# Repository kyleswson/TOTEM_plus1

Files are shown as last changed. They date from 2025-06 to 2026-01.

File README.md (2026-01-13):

<picture align="center">
  <source media="(prefers-color-scheme: dark)" srcset="/docs/images/TOTEM_logo_dark.svg">
  <source media="(prefers-color-scheme: light)" srcset="/docs/images/TOTEM_logo_bright.svg">
  TOTEM logo
</picture>

<h1 align="center">T O T E M</h1>

TOTEM is a 38 key column-staggered choc split keyboard. It is meant to be used with a [Seeed Studio XIAO nRF52840 BLE](https://www.seeedstudio.com/Seeed-XIAO-BLE-nRF52840-p-5201.html) or [XIAO RP2040](https://www.seeedstudio.com/XIAO-RP2040-v1-0-p-5026.html).
It was created for the SEEED XIAO keyboard contest.\
[Here](https://www.hackster.io/geist/totem-a-tiny-splitkeyboard-with-splay-cb2e43) you can read about the process of making it.

## Companion Totem (TOTEM+1)
Totem+1 is a modified version of TOTEM by GEIGEIGEIST. It has additional one key on inner index column of each side (total 40 keys). This is because typing in Korean needs the "B" key on the right hand side. So I added additional B key on the right. And to make this keyboard symmetrical, I added it on the left side too. 

The inner thumb keys have been replaced to [EVQWGD001 roller encoders](https://a.aliexpress.com/_c3mfh3fF). Thought this will be handy for navigating cursor while typing. These are very expensive now(25$ for 1) but luckily I got it for 5$ each few years ago. \
I also found some alternatives that you can consider. But you may need to edit the PCB since the footprint will be different.\
https://github.com/kumamuk-git/CKW12 \
https://github.com/Taro-Hayashi/THQWGD001 \
https://github.com/EverydayErgo/MEH01 

For the batteries, I used this [305060 1100mAh battery](https://a.aliexpress.com/_c3kIPq6d) since I wanted long battery life. 

***

## LAYOUT

TOTEM layout

***

## PCB

[Here](/PCB/) you can find the KiCad files and Gerbers for the TOTEM.

***

## CASE

You can use the TOTEM without a case, but [here](/case/) you can find one I made for it.

***

## BUILD GUIDE

The build guide for the TOTEM can be found [here](/docs/buildguide.md).

***

## FIRMWARE

[QMK (VIAL) precompiled](/firmware/QMK/) or [QMK (VIAL) source](/firmware/QMK/VIAL_source/) for the TOTEM (wired using the XIAO RP2040)\
[ZMK precompiled](/firmware/ZMK/) or [ZMK source (outdated)](https://github.com/GEIGEIGEIST/zmk-config-totem) for the TOTEM (wireless using the XIAO BLE)

***

## BUY

You can buy TOTEM kits and finished builds on [keeb.supply](https://keeb.supply/products/geist-totem) (based in Germany)

***

## PHOTOS

This is the TOTEM in a black resin case

TOTEM black resin\
TOTEM black resin\
TOTEM black resin

This is the TOTEM with a black resin tenting bottom plate

TOTEM black resin tenting\
[Video by *Wolfgang's Channel* showing the tenting system in action](https://youtu.be/rvM2BthjEI4?si=mTJVdPeZstshnDyo)

***

## CREDITS

### INSPIRATION

I've added the additional pinky key to make the TOTEM compatible with the layout boards like the [Balbuzard](https://github.com/brow/balbuzard) by [Tom Brow](https://github.com/brow) and the [Osprette](https://github.com/smores56/osprette) by [Sam Mohr](https://github.com/smores56) use, where you put the keybinding of the top left and right keys on an outer pinky key.

### HELP FIXING THINGS

People who helped me create this board and fix stuff

#### PCB
- [Marco "Bob"](https://github.com/GroooveBob)

#### CASE
- [Freya](https://github.com/freya-irl)
- [Bubbleology](https://github.com/bubbleology)

#### FIRMWARE
- [Cem Aksoylar](https://github.com/caksoylar)
- [Grinnie](https://github.com/regicidalplutophage)
- [Alaa Saad Mansour](https://github.com/AlaaSaadAbdo)
- [pekudzu](https://github.com/pekudzu)

If you build a TOTEM I would be pretty happy to see some pictures. And if you want to leave me a tip you can do this [here](https://ko-fi.com/geigeigeist) (but please don't feel pressured)

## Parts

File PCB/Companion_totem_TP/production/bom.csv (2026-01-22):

Designator | Footprint | Quantity | Value | LCSC Part #
BAT+1 | BatteryPad | 1 | +
BATGND1 | BatteryPad | 1 | -
DL1, DL10, DL11, DL12, DL13, DL14, DL15, DL16, DL17, DL18, DL19, DL2, DL20, DL3, DL4, DL5, DL6, DL7, DL8, DL9 | Diode_SOD123 | 20 | D_Small
ENCL17 | RollerEncoder+SW_horizontal | 1 | RotaryEncoder_Switch
J1 | JST_PH_reversible | 1 | Conn_01x02_Socket
PSW1 | MSK12C02 | 1 | SW_SPDT
RSW1 | SKHLLCA010 | 1 | SW_Push
SWL1, SWL10, SWL11, SWL12, SWL13, SWL14, SWL15, SWL16, SWL18, SWL19, SWL2, SWL20, SWL3, SWL4, SWL5, SWL6, SWL7, SWL8, SWL9 | SW_Hotswap_Kailh_Choc_V1V2 | 19 | SW_Push_45deg
U1 | xiao-ble-smd-cutout | 1 | xiao-ble

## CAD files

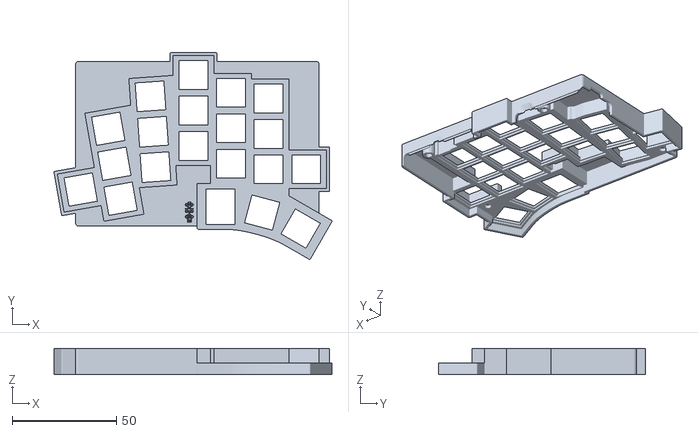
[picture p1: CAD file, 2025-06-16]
case/Totem_rollin/Totem_rollin_top_left.stl
133.1 x 99.0 x 12.5

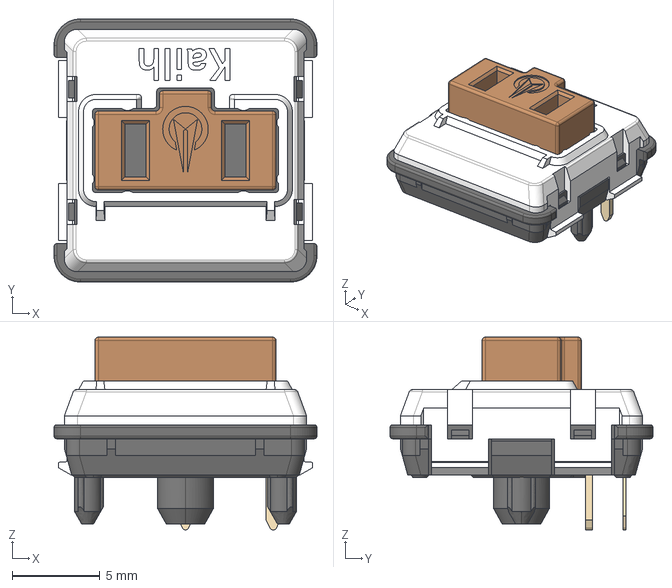
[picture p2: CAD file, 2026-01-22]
PCB/Companion_totem_TP/TOTEM3D/SW_Kailh_Choc_V1.stp
15.0 x 15.0 x 11.0 mm

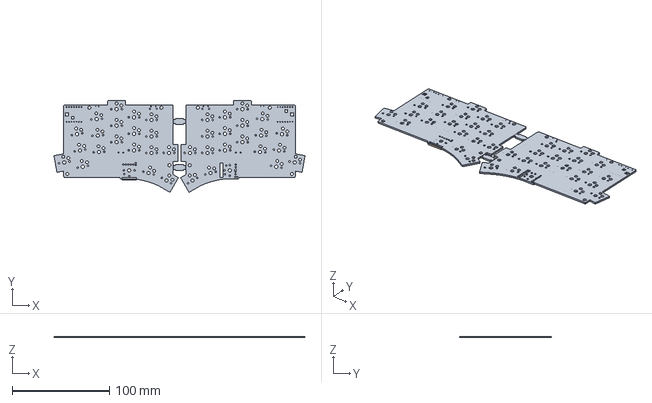
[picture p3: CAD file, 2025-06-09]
PCB/totem_0_2.step
258.7 x 94.4 x 1.51 mm
Totem_rollin_PCB_1
Totem_rollin_PCB_2

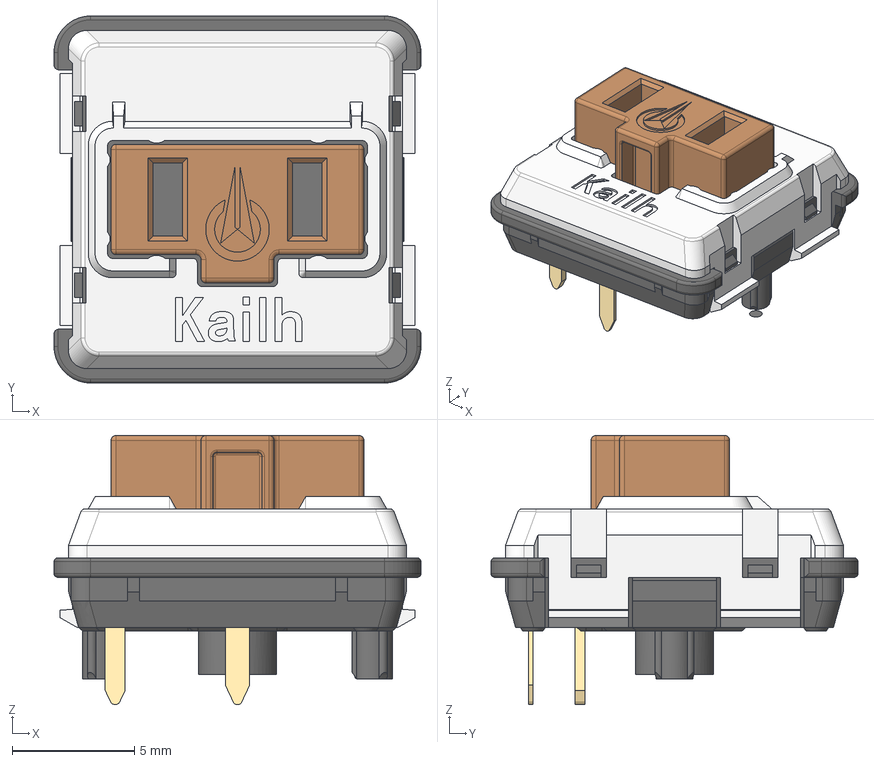
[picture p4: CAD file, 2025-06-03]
PCB/Companion_totem_TP/TOTEM3D/Kailh_switch_PG1350_optional.step
15.0 x 15.0 x 11.0 mm

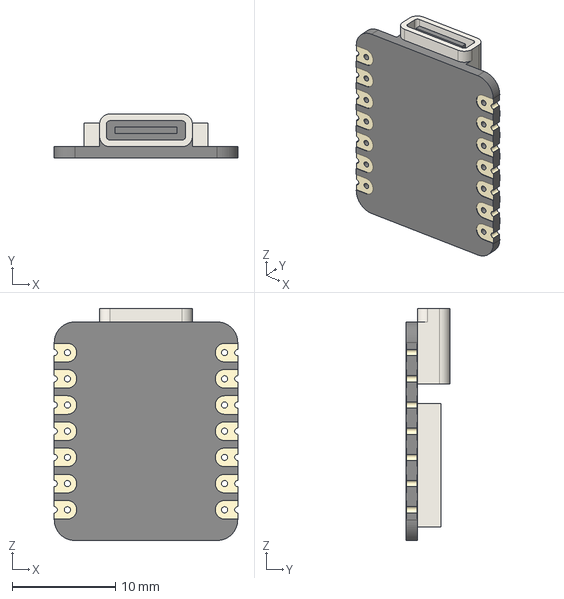
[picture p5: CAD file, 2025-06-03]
PCB/Companion_totem_TP/TOTEM3D/xiao-ble-tht.step
17.8 x 4.27 x 22.5 mm

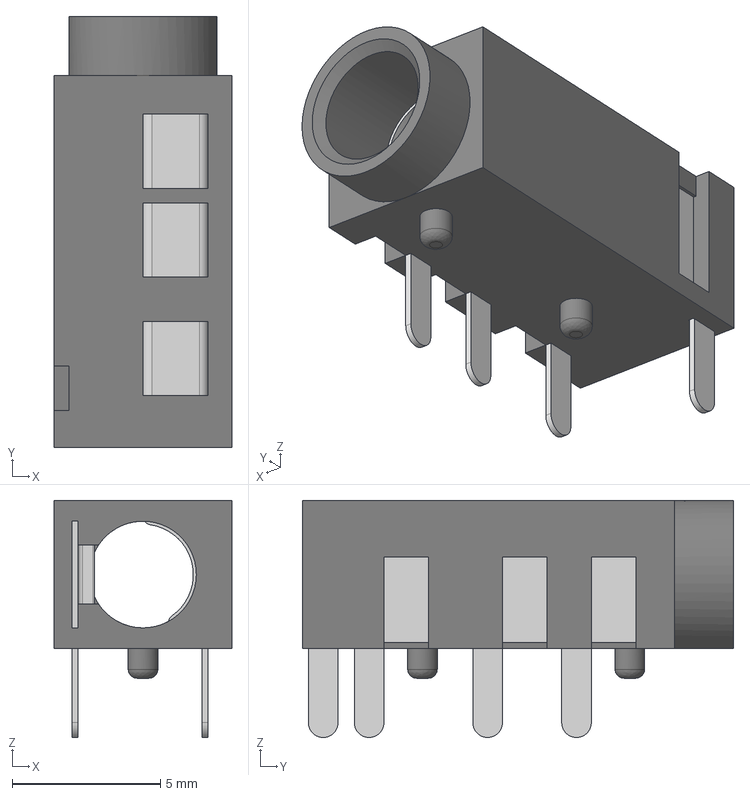
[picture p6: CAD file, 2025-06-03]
PCB/Companion_totem_TP/TOTEM3D/PJ320A.STEP
6.00 x 14.6 x 8.00 mm

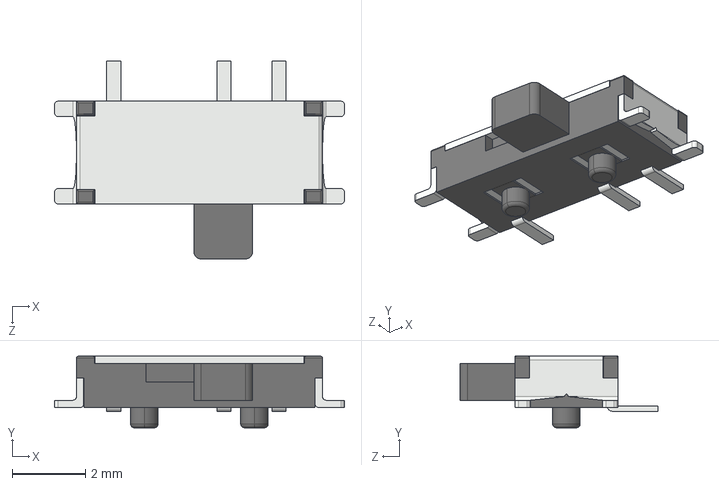
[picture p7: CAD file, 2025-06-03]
PCB/Companion_totem_TP/TOTEM3D/MSK12C02.STEP
7.90 x 1.95 x 5.39 mm

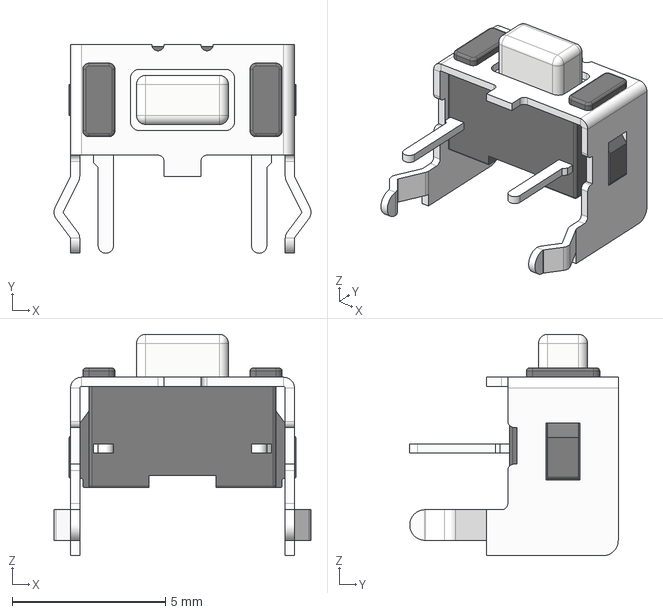
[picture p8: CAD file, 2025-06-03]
PCB/Companion_totem_TP/TOTEM3D/SW_SKHLLC.step
8.38 x 6.80 x 7.22 mm

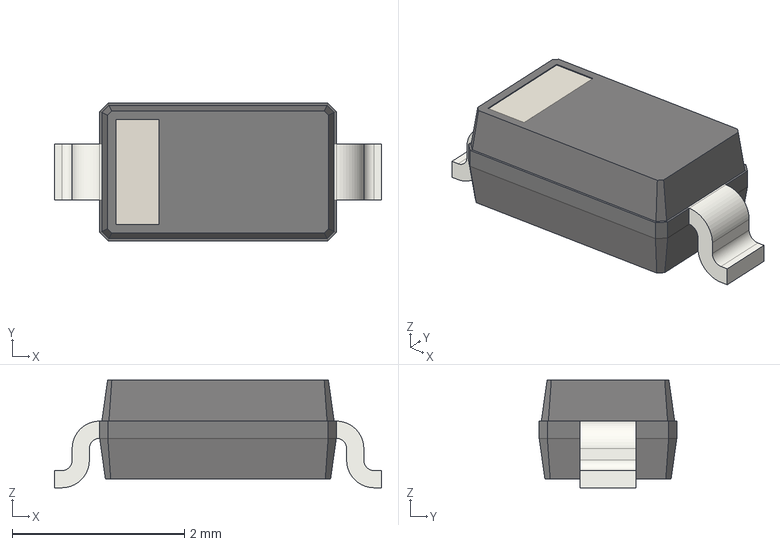
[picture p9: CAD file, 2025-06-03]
PCB/Companion_totem_TP/TOTEM3D/D_SOD-123.step
3.80 x 1.60 x 1.25 mm

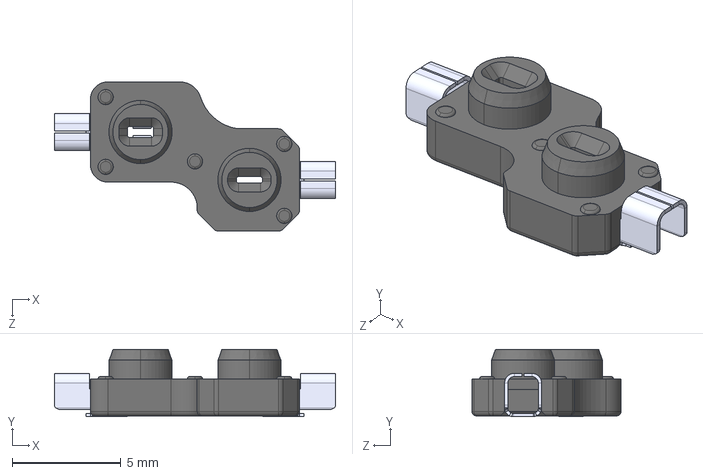
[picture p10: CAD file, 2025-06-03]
PCB/Companion_totem_TP/TOTEM3D/Kailh_socket_PG1350_optional.STEP
12.9 x 3.09 x 6.85 mm
pin x 2
socket

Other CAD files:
case/Totem_rollin/TOTEM_ROLLIN_case_ble.f3d

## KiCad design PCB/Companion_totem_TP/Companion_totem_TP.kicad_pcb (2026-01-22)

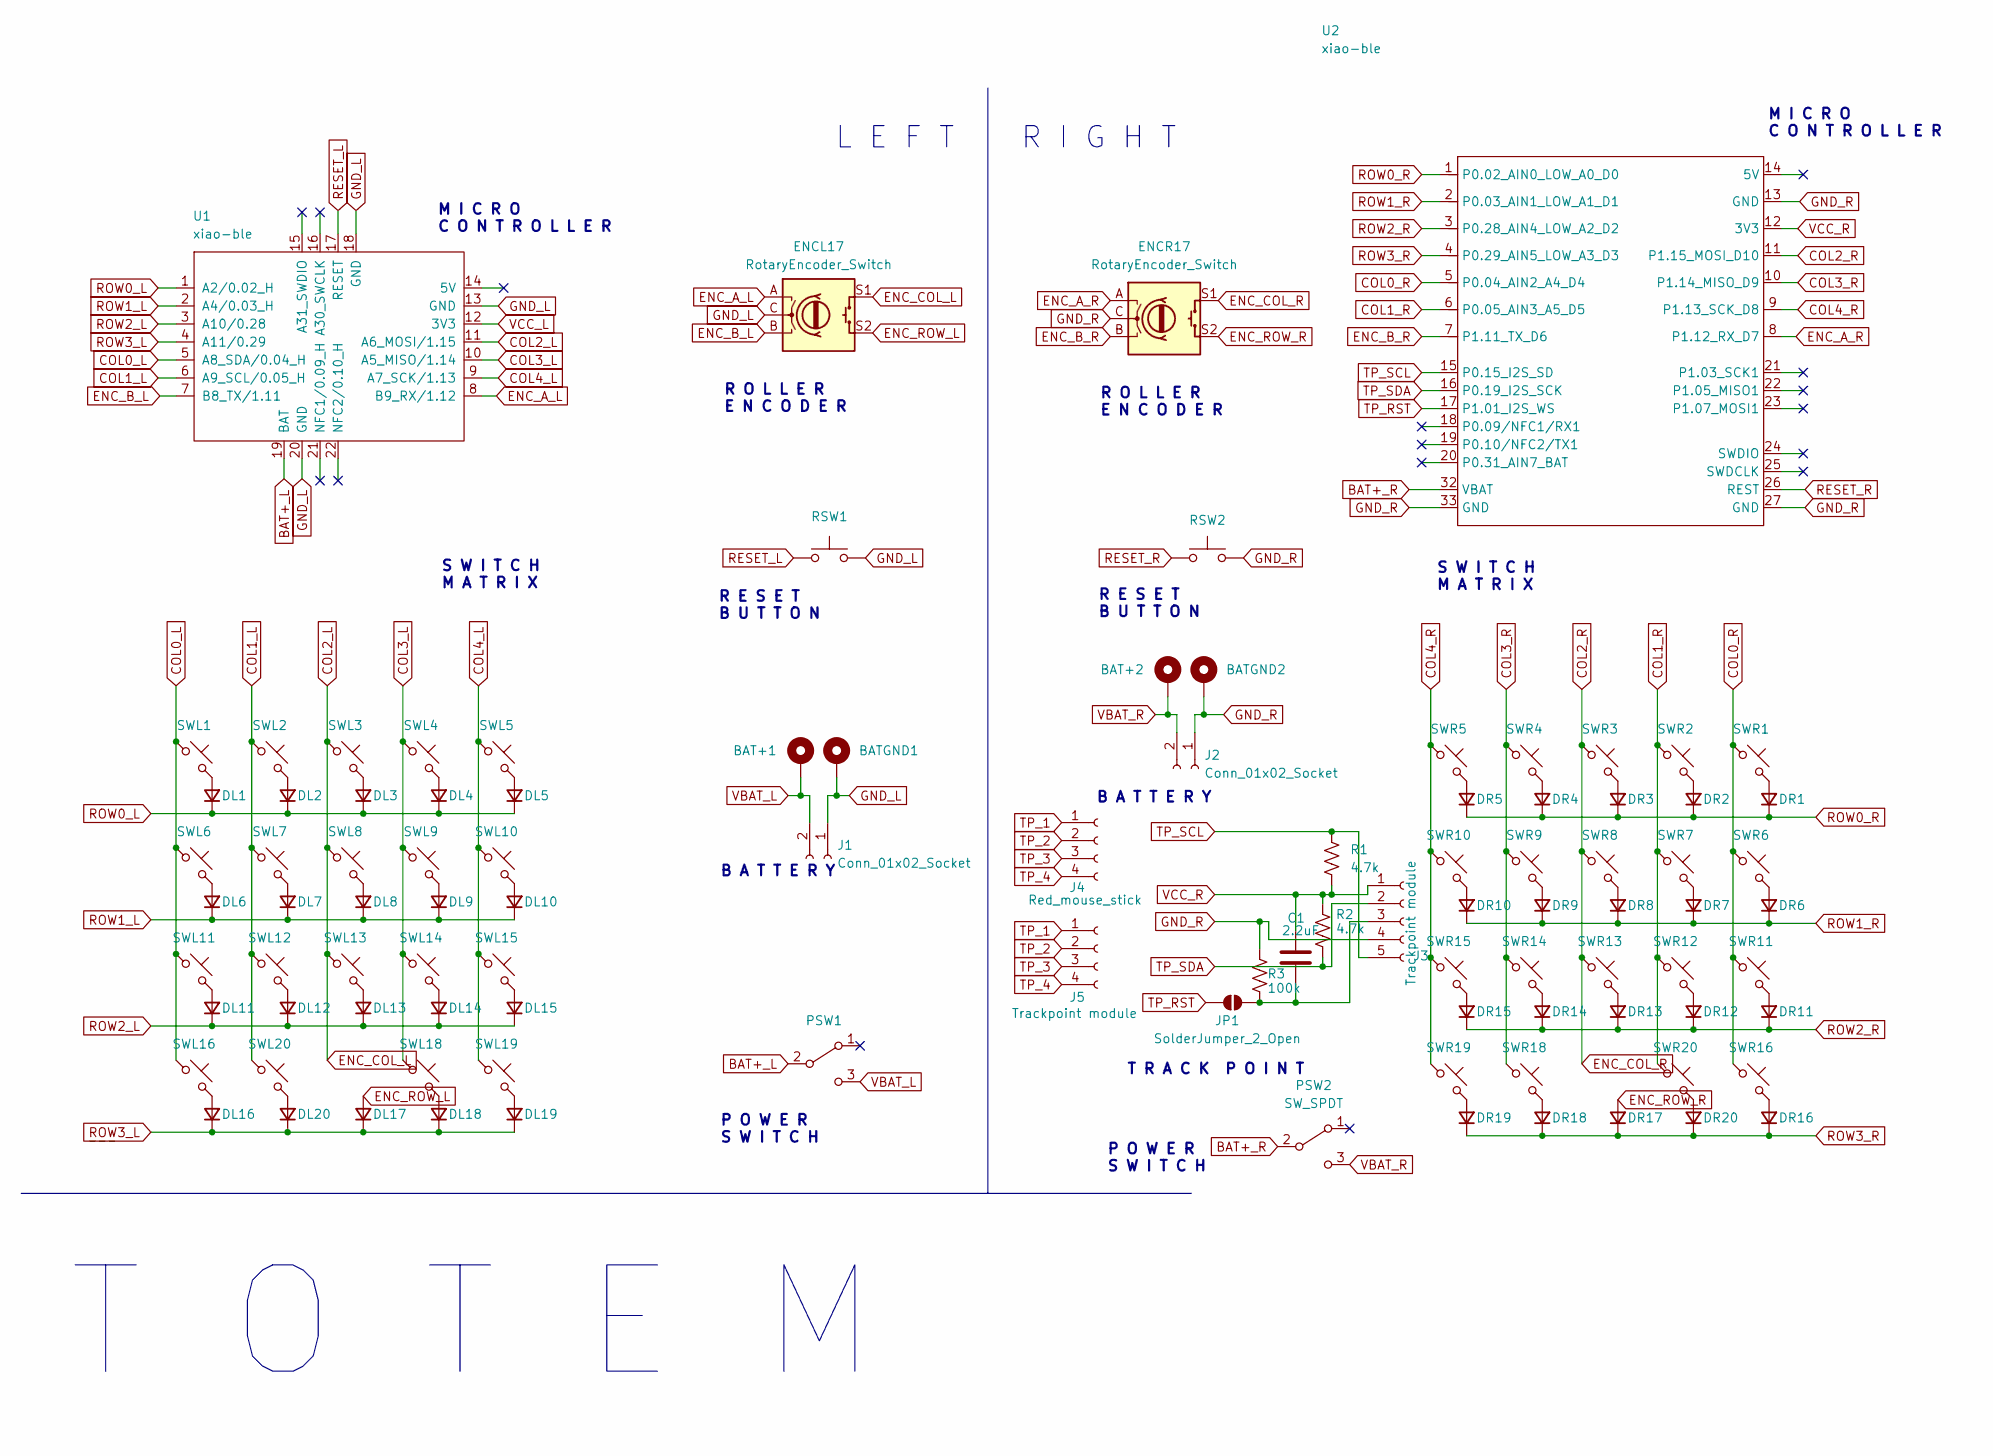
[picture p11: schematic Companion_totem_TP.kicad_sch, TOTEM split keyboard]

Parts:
BAT+1, BAT+2: +; BatteryPad
BATGND1, BATGND2: -; BatteryPad
C1: 2.2uF; C_0603_1608Metric_Pad1.08x0.95mm_HandSolder
DL1, DL2, DL3, DL4, DL5, DL6, DL7, DL8, DL9, DL10, DL11, DL12, DL13, DL14, DL15, DL16, DL17, DL18, DL19, DL20: D_Small; Diode_SOD123
DR1, DR2, DR3, DR4, DR5, DR6, DR7, DR8, DR9, DR10, DR11, DR12, DR13, DR14, DR15, DR16, DR17, DR18, DR19, DR20: D_Small; Diode_SOD123
ENCL17: RotaryEncoder_Switch; RollerEncoder+SW_horizontal
ENCR17: RotaryEncoder_Switch; RollerEncoder_SW_Vertical
J1, J2: Conn_01x02_Socket
J3: Trackpoint module; PinSocket_1x05_P2.54mm_Vertical
J4: Red_mouse_stick; T460S_TP
J5: Trackpoint module; TP_input
JP1: SolderJumper_2_Open; Jumper
PSW1, PSW2: SW_SPDT; MSK12C02
R1, R2: 4.7k; R_0603_1608Metric_Pad0.98x0.95mm_HandSolder
R3: 100k; R_0603_1608Metric_Pad0.98x0.95mm_HandSolder
RSW1, RSW2: SW_Push; SKHLLCA010
SWL1, SWL2, SWL3, SWL4, SWL5, SWL6, SWL7, SWL8, SWL9, SWL10, SWL11, SWL12, SWL13, SWL14, SWL15, SWL16, SWL18, SWL19, SWL20: SW_Push_45deg; Kailh_socket_PG1350
SWR1, SWR2, SWR3, SWR4, SWR5, SWR6, SWR7, SWR8, SWR9, SWR10, SWR11, SWR12, SWR13, SWR14, SWR15, SWR16, SWR18, SWR19, SWR20: SW_Push_45deg; Kailh_socket_PG1350
U1: xiao-ble; xiao-ble-smd-cutout
U2: xiao-ble; XIAO-nRF52840-Plus-SMD

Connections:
BAT+_L: PSW1.2 (B), U1.19 (BAT)
BAT+_R: PSW2.2 (B), U2.32 (VBAT)
COL0_L: SWL1.1, SWL6.1, SWL11.1, SWL16.1, U1.5 (A8_SDA/0.04_H)
COL0_R: SWR1.1, SWR6.1, SWR11.1, SWR16.1, U2.5 (P0.04_AIN2_A4_D4)
COL1_L: SWL2.1, SWL7.1, SWL12.1, SWL20.1, U1.6 (A9_SCL/0.05_H)
COL1_R: SWR2.1, SWR7.1, SWR12.1, SWR20.1, U2.6 (P0.05_AIN3_A5_D5)
COL2_L: ENCL17.S1, SWL3.1, SWL8.1, SWL13.1, U1.11 (A6_MOSI/1.15)
COL2_R: ENCR17.1, ENCR17.2, ENCR17.S1, SWR3.1, SWR8.1, SWR13.1, U2.11 (P1.15_MOSI_D10)
COL3_L: SWL4.1, SWL9.1, SWL14.1, SWL18.1, U1.10 (A5_MISO/1.14)
COL3_R: SWR4.1, SWR9.1, SWR14.1, SWR18.1, U2.10 (P1.14_MISO_D9)
COL4_L: SWL5.1, SWL10.1, SWL15.1, SWL19.1, U1.9 (A7_SCK/1.13)
COL4_R: SWR5.1, SWR10.1, SWR15.1, SWR19.1, U2.9 (P1.13_SCK_D8)
ENC_A_L: ENCL17.A, U1.8 (B9_RX/1.12)
ENC_A_R: ENCR17.A, U2.8 (P1.12_RX_D7)
ENC_B_L: ENCL17.B, U1.7 (B8_TX/1.11)
ENC_B_R: ENCR17.B, U2.7 (P1.11_TX_D6)
ENC_ROW_L: DL17.2 (A), ENCL17.S2
ENC_ROW_R: DR17.2 (A), ENCR17.1, ENCR17.2, ENCR17.S2
GND_L: BATGND1.1, ENCL17.C, J1.1, RSW1.2, U1.13 (GND), U1.18 (GND), U1.20 (GND)
GND_R: BATGND2.1, ENCR17.C, J2.1, J3.4, R3.1, RSW2.2, U2.13 (GND), U2.27 (GND), U2.33 (GND); also elsewhere on the board
unnamed: DL1.2 (A), SWL1.2
unnamed: DL2.2 (A), SWL2.2
unnamed: DL3.2 (A), SWL3.2
unnamed: DL4.2 (A), SWL4.2
unnamed: DL5.2 (A), SWL5.2
unnamed: DL6.2 (A), SWL6.2
unnamed: DL7.2 (A), SWL7.2
unnamed: DL8.2 (A), SWL8.2
unnamed: DL9.2 (A), SWL9.2
unnamed: DL10.2 (A), SWL10.2
unnamed: DL11.2 (A), SWL11.2
unnamed: DL12.2 (A), SWL12.2
unnamed: DL13.2 (A), SWL13.2
unnamed: DL14.2 (A), SWL14.2
unnamed: DL15.2 (A), SWL15.2
unnamed: DL16.2 (A), SWL16.2
unnamed: DL18.2 (A), SWL18.2
unnamed: DL19.2 (A), SWL19.2
unnamed: DL20.2 (A), SWL20.2
unnamed: DR1.2 (A), SWR1.2
unnamed: DR2.2 (A), SWR2.2
unnamed: DR3.2 (A), SWR3.2
unnamed: DR4.2 (A), SWR4.2
unnamed: DR5.2 (A), SWR5.2
unnamed: DR6.2 (A), SWR6.2
unnamed: DR7.2 (A), SWR7.2
unnamed: DR8.2 (A), SWR8.2
unnamed: DR9.2 (A), SWR9.2
unnamed: DR10.2 (A), SWR10.2
unnamed: DR11.2 (A), SWR11.2
unnamed: DR12.2 (A), SWR12.2
unnamed: DR13.2 (A), SWR13.2
unnamed: DR14.2 (A), SWR14.2
unnamed: DR15.2 (A), SWR15.2
unnamed: DR16.2 (A), SWR16.2
unnamed: DR18.2 (A), SWR18.2
unnamed: DR19.2 (A), SWR19.2
unnamed: DR20.2 (A), SWR20.2
unnamed 58: C1.2, J3.3, JP1.2 (B), R3.2; also elsewhere on the board
RESET_L: RSW1.1, U1.17 (RESET)
RESET_R: RSW2.1, U2.26 (REST)
ROW0_L: DL1.1 (K), DL2.1 (K), DL3.1 (K), DL4.1 (K), DL5.1 (K), U1.1 (A2/0.02_H)
ROW0_R: DR1.1 (K), DR2.1 (K), DR3.1 (K), DR4.1 (K), DR5.1 (K), U2.1 (P0.02_AIN0_LOW_A0_D0)
ROW1_L: DL6.1 (K), DL7.1 (K), DL8.1 (K), DL9.1 (K), DL10.1 (K), U1.2 (A4/0.03_H)
ROW1_R: DR6.1 (K), DR7.1 (K), DR8.1 (K), DR9.1 (K), DR10.1 (K), U2.2 (P0.03_AIN1_LOW_A1_D1)
ROW2_L: DL11.1 (K), DL12.1 (K), DL13.1 (K), DL14.1 (K), DL15.1 (K), U1.3 (A10/0.28)
ROW2_R: DR11.1 (K), DR12.1 (K), DR13.1 (K), DR14.1 (K), DR15.1 (K), U2.3 (P0.28_AIN4_LOW_A2_D2)
ROW3_L: DL16.1 (K), DL17.1 (K), DL18.1 (K), DL19.1 (K), DL20.1 (K), U1.4 (A11/0.29)
ROW3_R: DR16.1 (K), DR17.1 (K), DR18.1 (K), DR19.1 (K), DR20.1 (K), U2.4 (P0.29_AIN5_LOW_A3_D3)
TP_1: J4.1, J5.1; also elsewhere on the board
TP_2: J4.2, J5.2; also elsewhere on the board
TP_3: J4.3, J5.3; also elsewhere on the board
TP_4: J4.4, J5.4; also elsewhere on the board
TP_RST: JP1.1 (A), U2.17 (P1.01_I2S_WS)
TP_SCL: J3.5, R1.1, U2.15 (P0.15_I2S_SD); also elsewhere on the board
TP_SDA: J3.2, R2.2, U2.16 (P0.19_I2S_SCK); also elsewhere on the board
VBAT_L: BAT+1.1, J1.2, PSW1.3 (C)
VBAT_R: BAT+2.1, J2.2, PSW2.3 (C)
VCC_L: U1.12 (3V3)
VCC_R: C1.1, J3.1, R1.2, R2.1, U2.12 (3V3); also elsewhere on the board

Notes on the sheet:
M I C R O C O N T R O L L E R
R E S E T B U T T O N
S W I T C H M A T R I X
P O W E R S W I T C H
T O T E M
B A T T E R Y
R O L L E R E N C O D E R
T R A C K P O I N T
R I G H T
L E F T

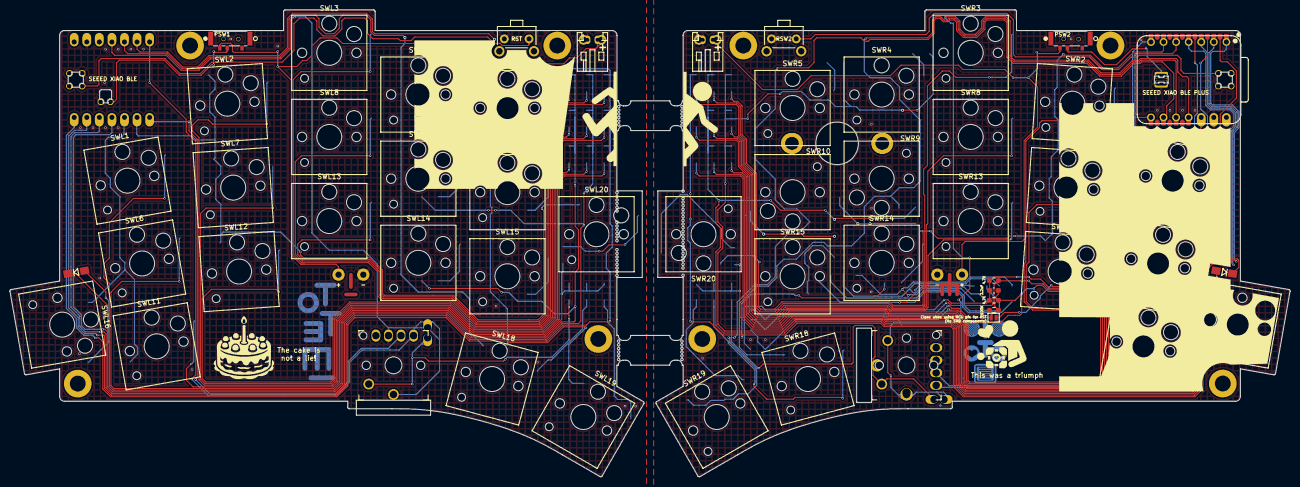
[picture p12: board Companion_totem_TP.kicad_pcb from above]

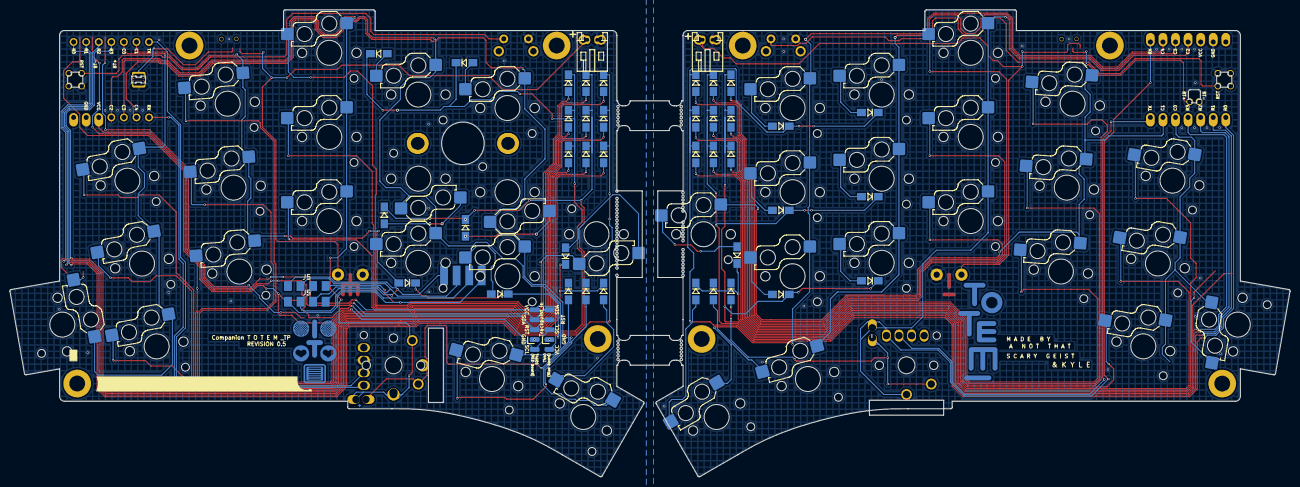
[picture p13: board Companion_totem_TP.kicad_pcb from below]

Board: 2 copper layers, 258.7 x 94.4 mm, 102 parts (40 on the bottom side), 79 nets.

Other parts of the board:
J5#2: Trackpoint module; TP_input
Trackpoint_in: Trackpoint module; PinSocket_1x05_P2.54mm_Vertical

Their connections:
GND_R: Trackpoint_in.4; also elsewhere on the board
unnamed 58: Trackpoint_in.2; also elsewhere on the board
TP_1: J5#2.1 (Pin_4); also elsewhere on the board
TP_2: J5#2.2 (Pin_3); also elsewhere on the board
TP_3: J5#2.3 (Pin_2); also elsewhere on the board
TP_4: J5#2.4 (Pin_1); also elsewhere on the board
TP_SCL: Trackpoint_in.3; also elsewhere on the board
TP_SDA: Trackpoint_in.1; also elsewhere on the board
VCC_R: Trackpoint_in.5; also elsewhere on the board

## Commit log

2025-06-03 new totemkyle
    [D_SOD-123.step, Kailh_socket_PG1350_optional.STEP, Kailh_switch_PG1350_optional.step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]
2025-06-04 add encoder & switch
    [Totemkyle.kicad_sch]
2025-06-05 Add 1 key and roller encoder
    [Totemkyle-B_Cu.gbl, Totemkyle-B_Mask.gbs, Totemkyle-B_Paste.gbp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]
2025-06-08 Added case
    [D_SOD-123.step, Kailh_socket_PG1350_optional.STEP, Kailh_switch_PG1350_optional.step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]
2025-06-18 add jst connector for battery
    [Totem_rollin.kicad_sch]
2026-01-13 Adding Track Point
    [Companion_totem_TP-B_Cu.gbl, Companion_totem_TP-B_Mask.gbs, Companion_totem_TP-B_Paste.gbp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]
2026-01-22 Added TP, Split L&R
    [Companion_totem_TP.kicad_pcb, Companion_totem_TP.kicad_sch, Companion_totem_TP_L.kicad_pcb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]
